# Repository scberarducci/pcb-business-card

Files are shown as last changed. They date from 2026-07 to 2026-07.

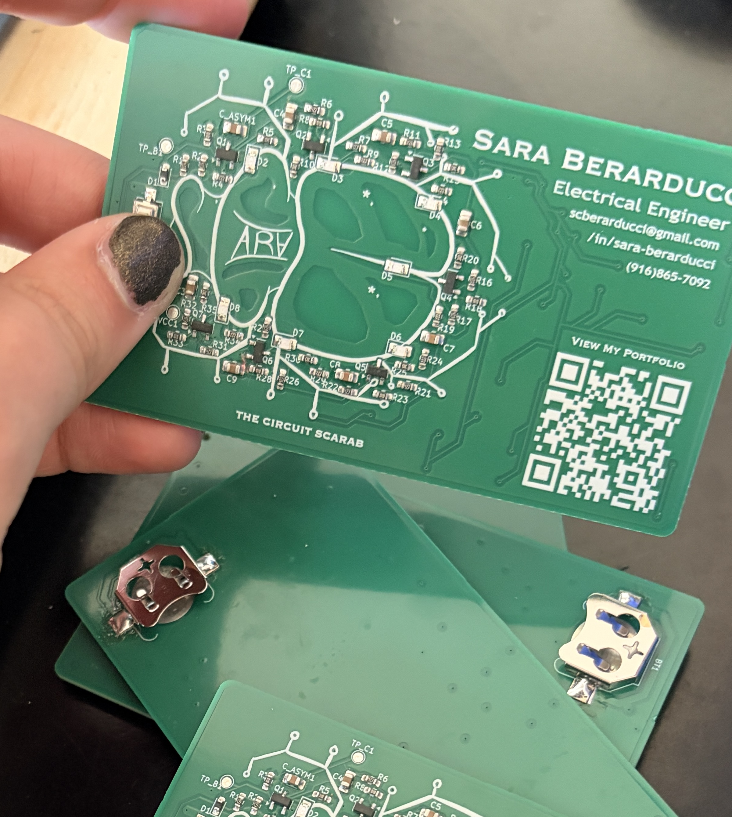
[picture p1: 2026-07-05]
demos/rev_1.0/fabricated_card.jpg

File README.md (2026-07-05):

# PCB Business Card
Design for Altium Academy's PCB Business Card Design Challenge (2026). Original design by Sara Berarducci. 
Open Hardware for educational use.

## License
*The hardware design files in this repository are licensed under the CERN Open Hardware Licence Version 2 - Weakly Reciprocal (CERN-OHL-W-2.0).*
*See LICENSE.txt for the full license text.*
*Educational use is encouraged, including use in classrooms and workshops.*
*Name, logo, and personal branding are **not** licensed for reuse except for attribution/reference purposes.*

## Description

This PCB business card is a functional 7-stage transistor loop oscillator visualized with LEDs. The loop oscillator is powered while a pushbutton is held and otherwise remains off.

The design includes startup asymmetry at the first stage using a capacitor and diode, which helps ensure consistent startup and quick reset when power is removed.

The included BOM contains all parts used in the original fabricated card, rev 1.0, except the coin cell holder, which is a Keystone 3000 CR1220 clip.

## Build Notes

The card was designed with JLCPCB's manufacturing capabilities in mind. It is powered by a CR1220 coin cell battery.

Voltage sag during extended use is expected. If the circuit is powered for long stretches of time, oscillation may slow and the LEDs may dim.

Rev 2.0 is currently in progress and will be added to this repository once completed. See the demos folder for images and videos of the fabricated card.

If you use this design to create a PCB of your own, I would love to see it! Feel free to email me at scberarducci@gmail.com or contact me on LinkedIn with your design.

## Repository Contents
* hardware/ — KiCad hardware design files and BOM
* demos/ — images and videos of the fabricated card
* logo/ — logo/reference assets used in the design - *not licensed for use other than for attribution purposes*

## Attribution
When using or sharing this design, attribution is requested.
**Sara Berarducci**
https://www.saraberarducci.com/hardware/altium-business-card-challenge

## Copyright
**Copyright (c) 2026 Sara Berarducci**

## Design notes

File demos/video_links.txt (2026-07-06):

Original breadboard circuit: 
https://drive.google.com/file/d/1XpT-ARhfIReBm9H97mOf5g29ecg2SI3U/view?usp=drive_link 

Fabricated card (rev 1.0):
https://drive.google.com/file/d/1Ts1VaveLqz0nB2ycd1Uyslbvo69Uqb5h/view?usp=drive_link

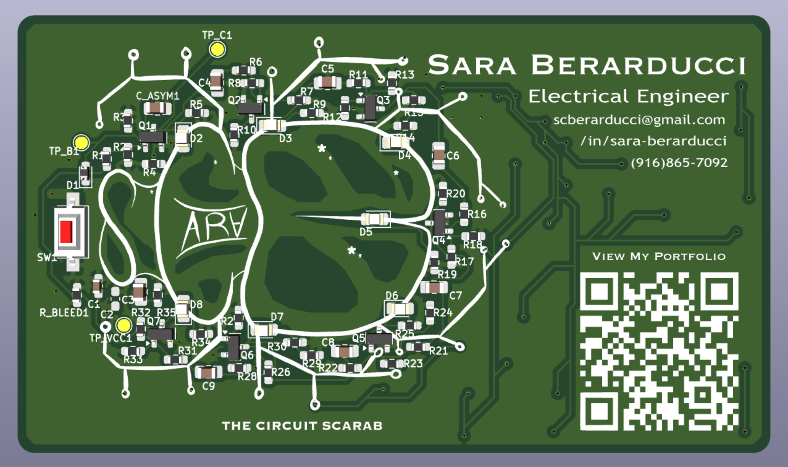
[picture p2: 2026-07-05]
demos/rev_1.0/3D_viewer.png

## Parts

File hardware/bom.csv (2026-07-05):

Designator | Footprint | Quantity | Value | LCSC Part #
BT1 | BatteryHolder_Keystone_3000_1x12mm | 1 | 3000
C1 | 0603 | 1 | 0.1uF
C2 | 0603 | 1 | 10uF
C3, C4, C5, C6, C7, C8, C9, C_ASYM1 | 0805 | 8 | 2.2uF
D1 | 0603 | 1 | D_ASYM
D2, D3, D4, D5, D6, D7, D8 | 0805 | 7 | LED
Q1, Q2, Q3, Q4, Q5, Q6, Q7 | SOT-23 | 7 | MMBT2222A
R1, R11, R16, R21, R26, R31, R6 | 0603 | 7 | 4.7k
R10, R15, R20, R25, R30, R35, R5 | 0603 | 7 | 10k
R12, R17, R2, R22, R27, R32, R7 | 0603 | 7 | 47k
R13, R18, R23, R28, R3, R33, R8, R_BLEED1 | 0603 | 8 | 100k
R14, R19, R24, R29, R34, R4, R9 | 0603 | 7 | 2.2k
SW1 | SW_SPST_CK_RS282G05A3 | 1 | SW_Push
TP_B1, TP_C1, TP_VCC1 | TestPoint_Pad_D1.5mm | 3 | TestPoint

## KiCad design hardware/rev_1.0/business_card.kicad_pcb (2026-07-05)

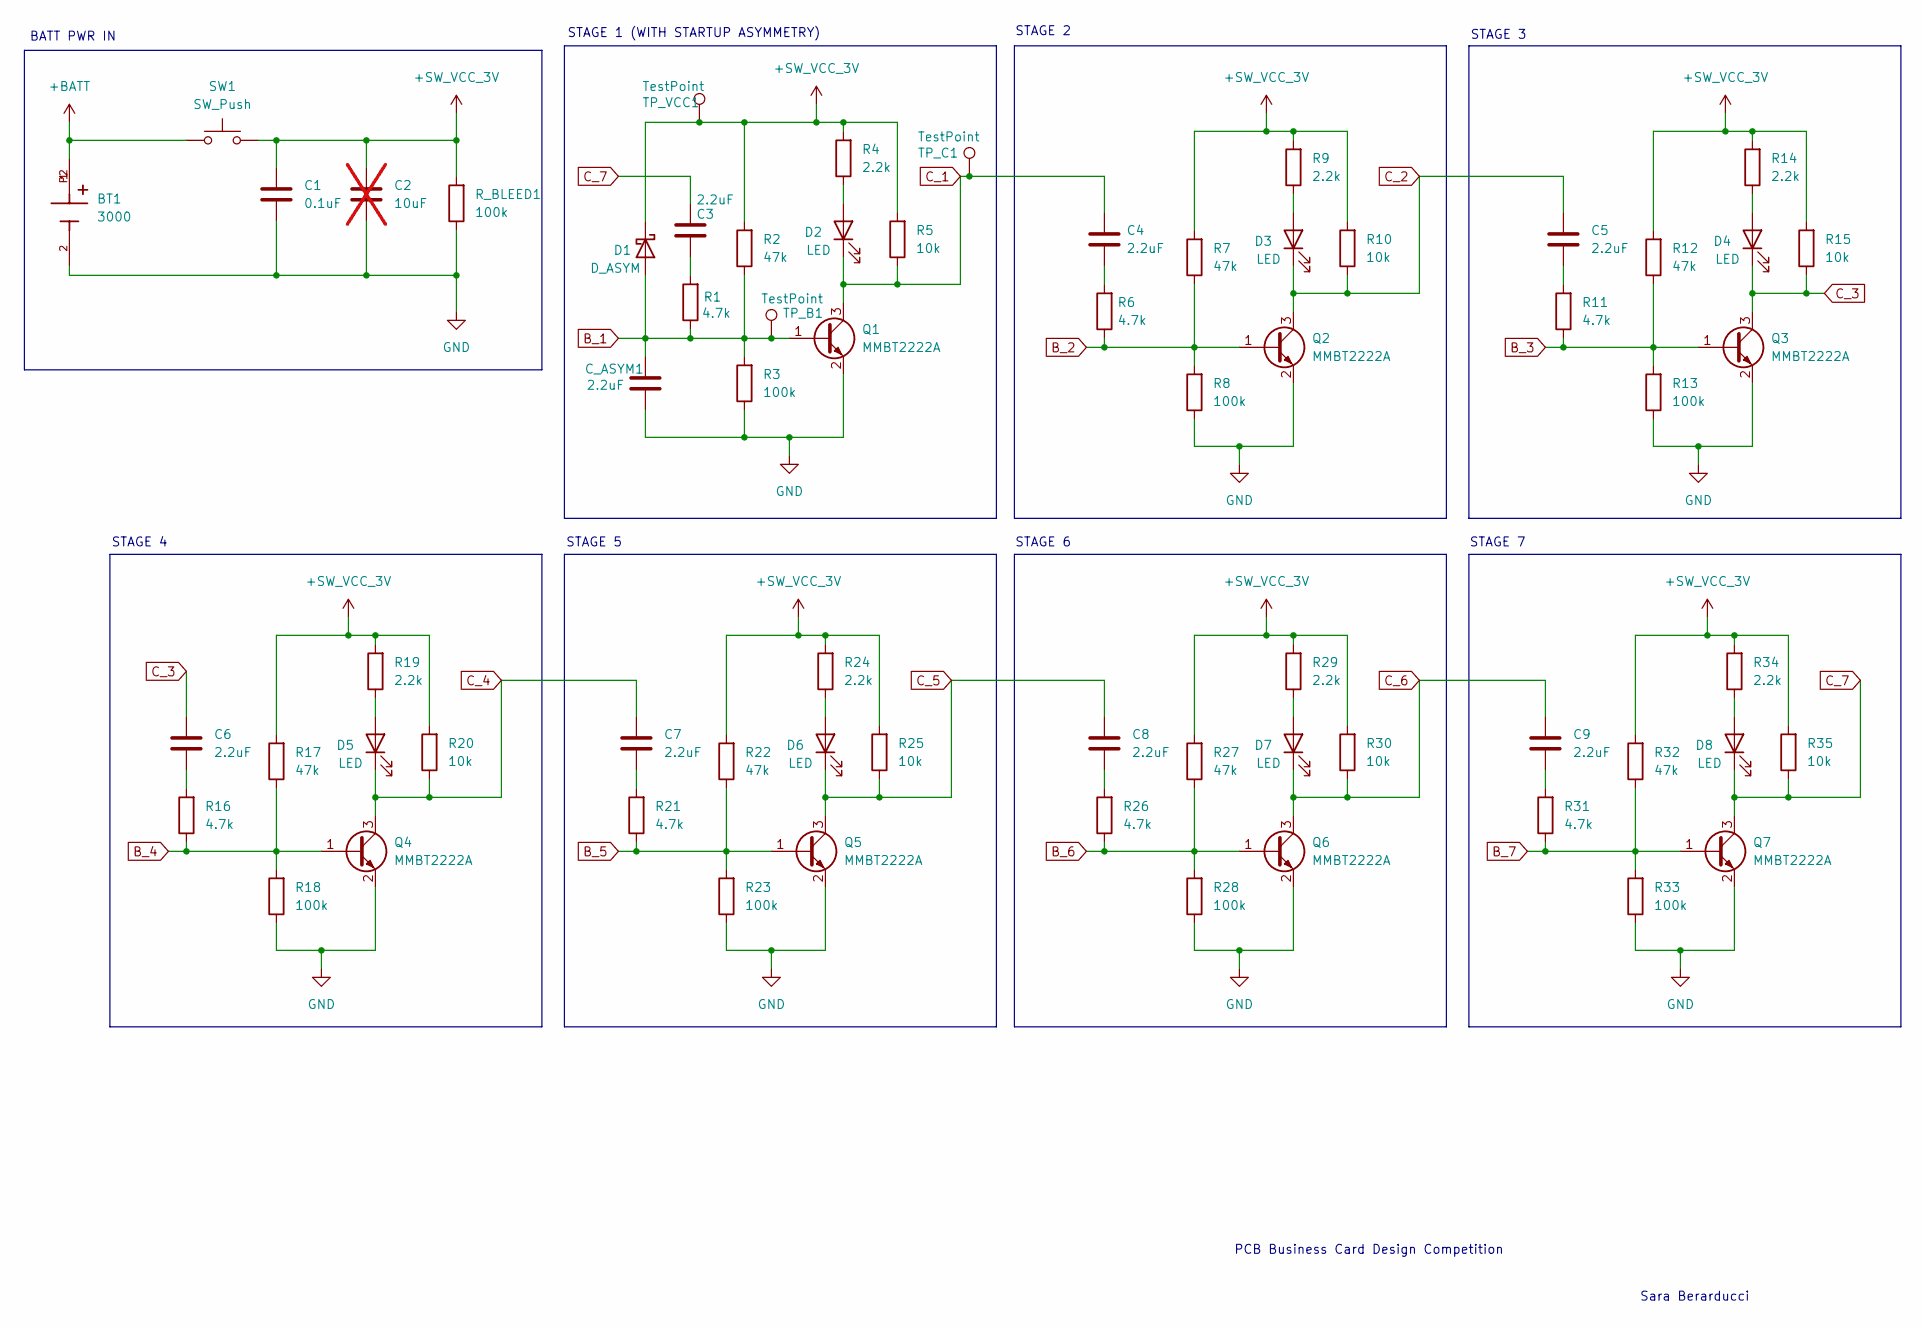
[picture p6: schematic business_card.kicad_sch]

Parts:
BT1: 3000; BatteryHolder_Keystone_3000_1x12mm; PARTREV M
C1: 0.1uF; C_0603_1608Metric_Pad1.08x0.95mm_HandSolder
C2: 10uF; C_0603_1608Metric_Pad1.08x0.95mm_HandSolder; not fitted
C3, C4, C5, C6, C7, C8, C9: 2.2uF; C_0805_2012Metric_Pad1.18x1.45mm_HandSolder
C_ASYM1: 2.2uF; C_0805_2012Metric_Pad1.18x1.45mm_HandSolder
D1: D_ASYM; D_0603_1608Metric_Pad1.05x0.95mm_HandSolder
D2, D3, D4, D5, D6, D7, D8: LED; LED_0805_2012Metric_Pad1.15x1.40mm_HandSolder
Q1, Q2, Q3, Q4, Q5, Q6, Q7: MMBT2222A; SOT-23
R1, R6, R11, R16, R21, R26, R31: 4.7k; R_0603_1608Metric_Pad0.98x0.95mm_HandSolder
R2, R7, R12, R17, R22, R27, R32: 47k; R_0603_1608Metric_Pad0.98x0.95mm_HandSolder
R3, R8, R13, R18, R23, R28, R33: 100k; R_0603_1608Metric_Pad0.98x0.95mm_HandSolder
R4, R9, R14, R19, R24, R29, R34: 2.2k; R_0603_1608Metric_Pad0.98x0.95mm_HandSolder
R5, R10, R15, R20, R25, R30, R35: 10k; R_0603_1608Metric_Pad0.98x0.95mm_HandSolder
R_BLEED1: 100k; R_0603_1608Metric_Pad0.98x0.95mm_HandSolder
SW1: SW_Push; SW_SPST_CK_RS282G05A3
TP_B1: TestPoint; TestPoint_Pad_D1.5mm
TP_C1: TestPoint; TestPoint_Pad_D1.5mm
TP_VCC1: TestPoint; TestPoint_Pad_D1.5mm

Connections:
+BATT: BT1.1, BT1.P2, SW1.1
+SW_VCC_3V: C1.1, C2.1, D1.1 (K), R2.2, R4.2, R5.2, R7.2, R9.2, R10.2, R12.2, R14.2, R15.2, R17.2, R19.2, R20.2, R22.2, R24.2, R25.2, R27.2, R29.2, R30.2, R32.2, R34.2, R35.2, R_BLEED1.2, SW1.2, TP_VCC1.1
B_1: C_ASYM1.2, D1.2 (A), Q1.1 (B), R1.1, R2.1, R3.2, TP_B1.1
B_2: Q2.1 (B), R6.1, R7.1, R8.2
B_3: Q3.1 (B), R11.1, R12.1, R13.2
B_4: Q4.1 (B), R16.1, R17.1, R18.2
B_5: Q5.1 (B), R21.1, R22.1, R23.2
B_6: Q6.1 (B), R26.1, R27.1, R28.2
B_7: Q7.1 (B), R31.1, R32.1, R33.2
C_1: C4.1, D2.1 (K), Q1.3 (C), R5.1, TP_C1.1
C_2: C5.1, D3.1 (K), Q2.3 (C), R10.1
C_3: C6.1, D4.1 (K), Q3.3 (C), R15.1
C_4: C7.1, D5.1 (K), Q4.3 (C), R20.1
C_5: C8.1, D6.1 (K), Q5.3 (C), R25.1
C_6: C9.1, D7.1 (K), Q6.3 (C), R30.1
C_7: C3.1, D8.1 (K), Q7.3 (C), R35.1
GND: BT1.2, C1.2, C2.2, C_ASYM1.1, Q1.2 (E), Q2.2 (E), Q3.2 (E), Q4.2 (E), Q5.2 (E), Q6.2 (E), Q7.2 (E), R3.1, R8.1, R13.1, R18.1, R23.1, R28.1, R33.1, R_BLEED1.1
unnamed: C3.2, R1.2
unnamed: C4.2, R6.2
unnamed: C5.2, R11.2
unnamed: C6.2, R16.2
unnamed: C7.2, R21.2
unnamed: C8.2, R26.2
unnamed: C9.2, R31.2
unnamed: D2.2 (A), R4.1
unnamed: D3.2 (A), R9.1
unnamed: D4.2 (A), R14.1
unnamed: D5.2 (A), R19.1
unnamed: D6.2 (A), R24.1
unnamed: D7.2 (A), R29.1
unnamed: D8.2 (A), R34.1

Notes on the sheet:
STAGE 3
STAGE 2
PCB Business Card Design Competition
STAGE 4
Sara Berarducci
STAGE 6
STAGE 1 (WITH STARTUP ASYMMETRY)
STAGE 5
STAGE 7
BATT PWR IN

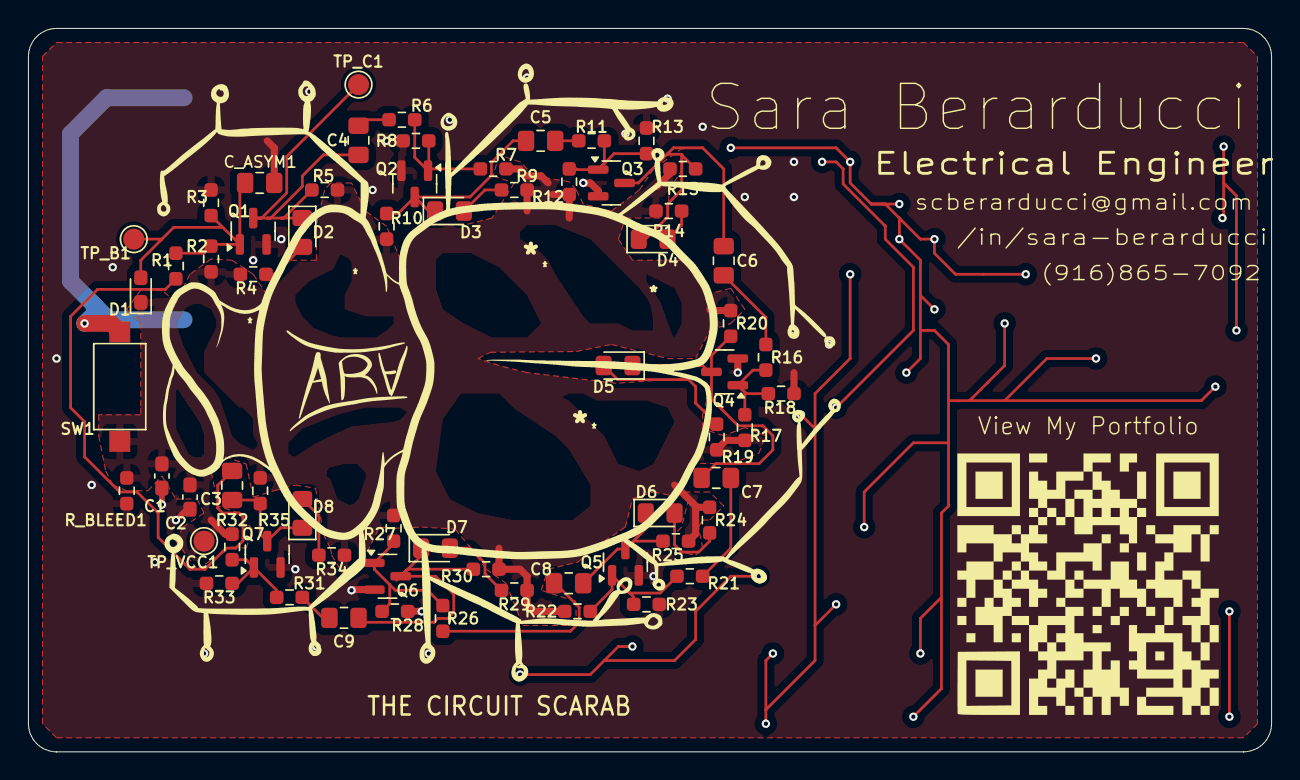
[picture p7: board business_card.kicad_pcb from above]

Board: 2 copper layers, 88.5 x 51.5 mm, 66 parts (1 on the bottom side), 31 nets.

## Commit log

2026-07-05 Add original hardware files via upload
    [bom.csv, business_card.kicad_pcb, business_card.kicad_sch]
2026-07-05 Rename hardware directory
    [bom.csv, business_card.kicad_pcb, business_card.kicad_sch]
2026-07-05 Added demos folder
    [bom.csv, business_card.kicad_pcb, business_card.kicad_sch]
